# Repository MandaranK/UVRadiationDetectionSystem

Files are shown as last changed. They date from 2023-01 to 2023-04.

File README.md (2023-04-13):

# UVRadiationDetectionSystem
Designed to take solar radiation as a voltage input value through the light sensor.
Programmed to convert it into a UV index value, to be displayed and updated on an LCD monitor, in addition to informing the user how much skin protection is needed outside.
The STM32 Microcontroller was programmed in C, using the STM32Cube IDE.
The outer structure was designed in Autodesk AutoCAD and later 3D printed.

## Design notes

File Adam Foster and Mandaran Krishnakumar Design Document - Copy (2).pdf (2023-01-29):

Adam Foster, Mandaran Krishnakumar

ECE 198

Design Document

Needs Assessment

Client/Customer Definition

The Customer for which the product is being built is an Electrical Engineer from Kingston

Jamaica, who spends a lot of time outside the in the sun when on jobsites, for example inspecting

solar panel installations done by his company. Jamaica is known for its tropical climate;

however, the temperatures can get exceedingly high, especially in the summer months. This puts

him as well as his employees at a high risk of overexposure to UV radiation, which can have

multiple adverse health effects. The UV protection device designed is intended to reduce the

possibility of these health effects by measuring the UV radiation index and giving a

recommendation for the level of protection needed to safely work in these environments. The age

of the customer as well as his employees also puts them at an increased risk of these health

effects, thus it is vital that this device can give a good idea of the protection level needed in order

to work safely. The customer also suggested that the total cost of the device should not exceed

100 CAD, making it accessible to a wider demographic to ensure the safety of all those who

work in the sun.

Sources Cited

Walker, N. (2015, September 11). NEPA urges Jamaicans to practice better sun habits to

prevent skin and eye damage. NEPA. Retrieved October 31, 2022, from

https://websitearchive2020.nepa.gov.jm/new/media_centre/press_releases/releases/2015/P

R20150911-nepa_urges_jamaicans_to_practice_better_sun_habits.php (https://websitearchive2020.nepa.gov.jm/new/media_centre/press_releases/releases/2015/PR20150911-nepa_urges_jamaicans_to_practice_better_sun_habits.php)

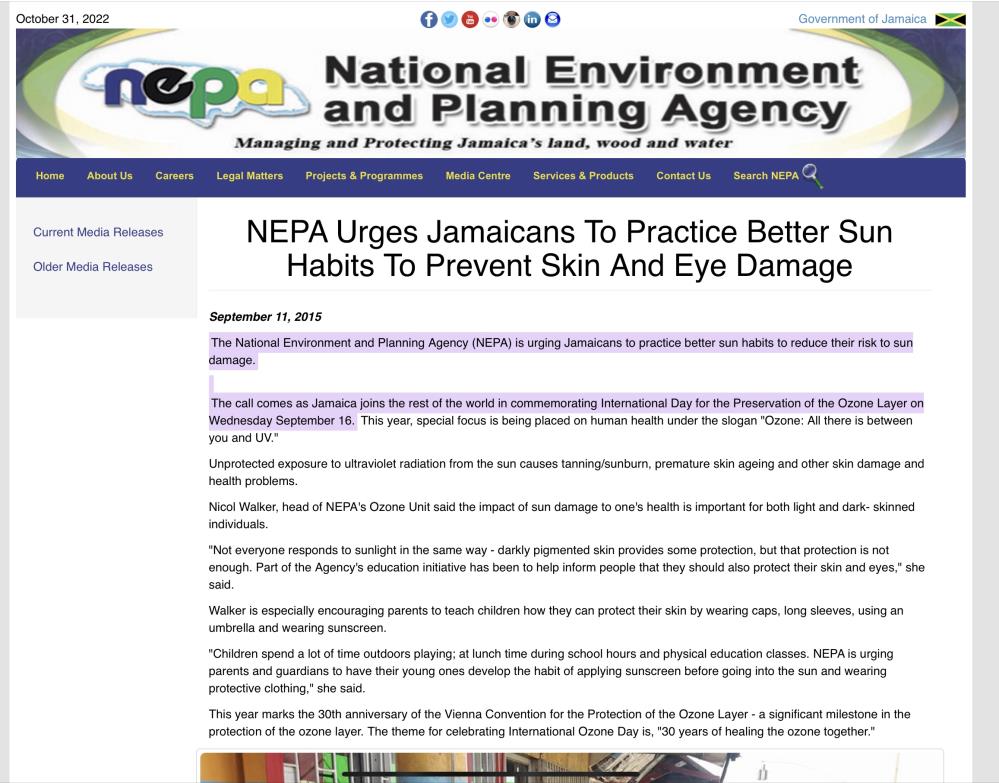
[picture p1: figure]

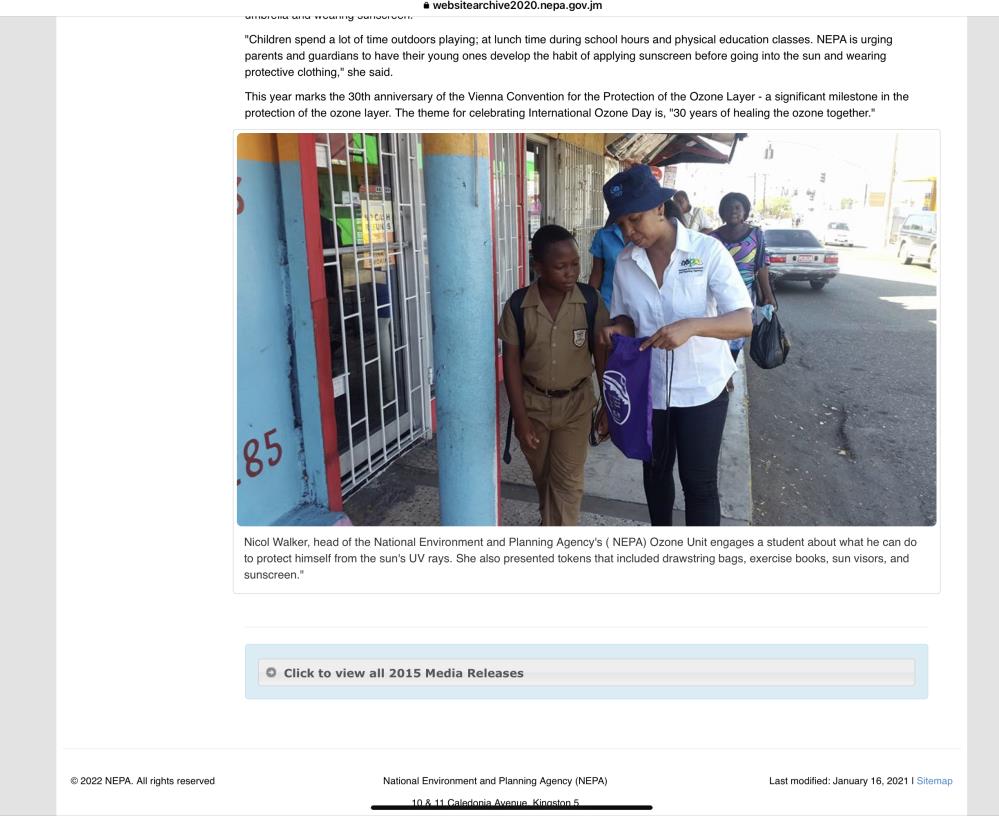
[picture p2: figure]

Rostant, H. (2001, July). Enjoy the fun, beware the sun. Caribbean Beat Magazine. Retrieved

October 31, 2022, from https://www.caribbean-beat.com/issue-50/enjoy-the-fun-beware-

the-sun#axzz7ifx9yx3c (https://www.caribbean-beat.com/issue-50/enjoy-the-fun-beware-the-sun#axzz7ifx9yx3c)

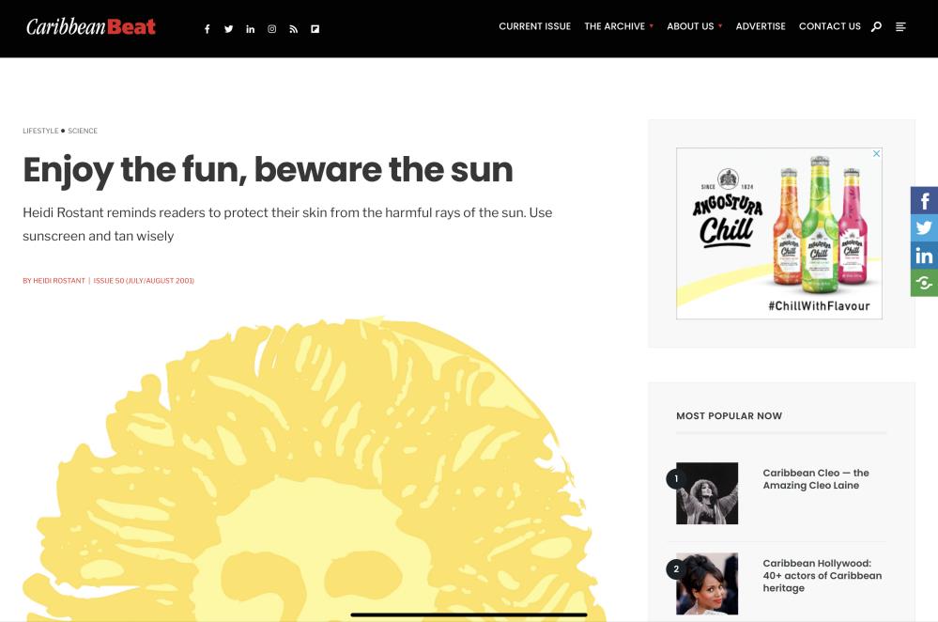
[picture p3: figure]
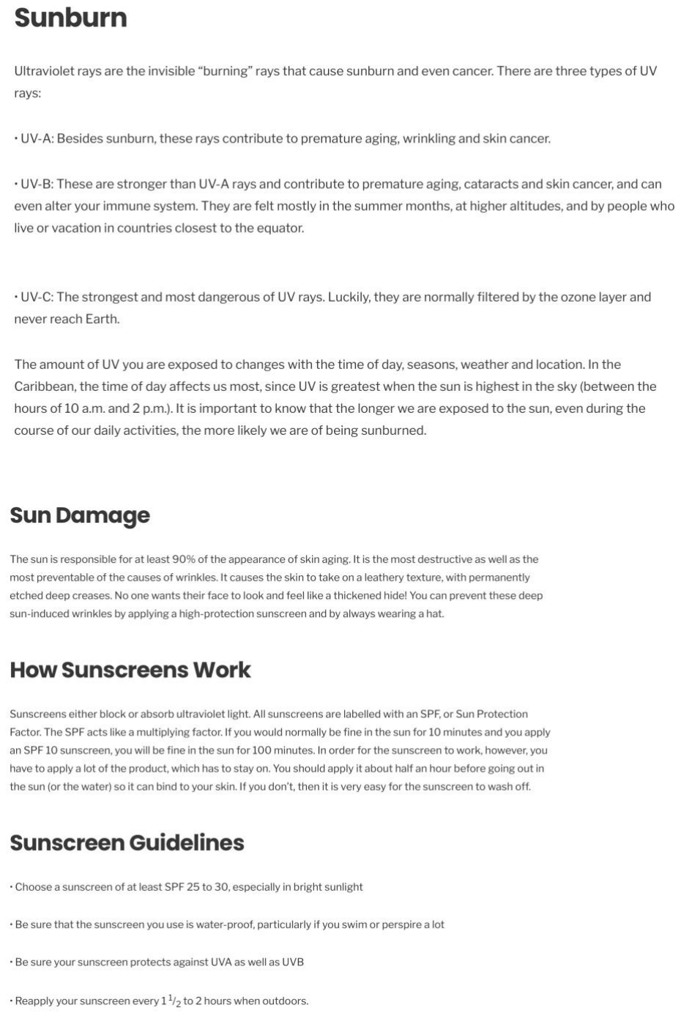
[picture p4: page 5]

Walker, N. (2009, January 27). The Ozone Layer and Jamaica's Role in Protecting It. National

Environment Planning Agency. Retrieved October 31, 2022, from

https://websitearchive2020.nepa.gov.jm/student/resource-

material/pdf/The_Ozone_Layer_and_Jamaica's_%20Role_in_Protecting_it.pdf (https://websitearchive2020.nepa.gov.jm/student/resource-material/pdf/The_Ozone_Layer_and_Jamaica's_%20Role_in_Protecting_it.pdf)

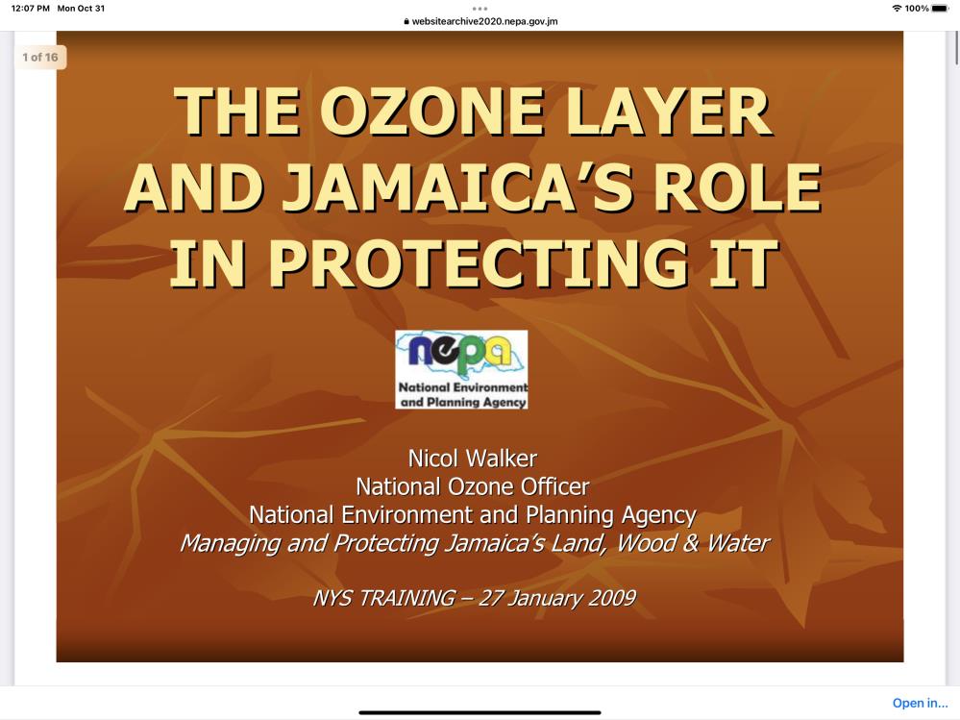
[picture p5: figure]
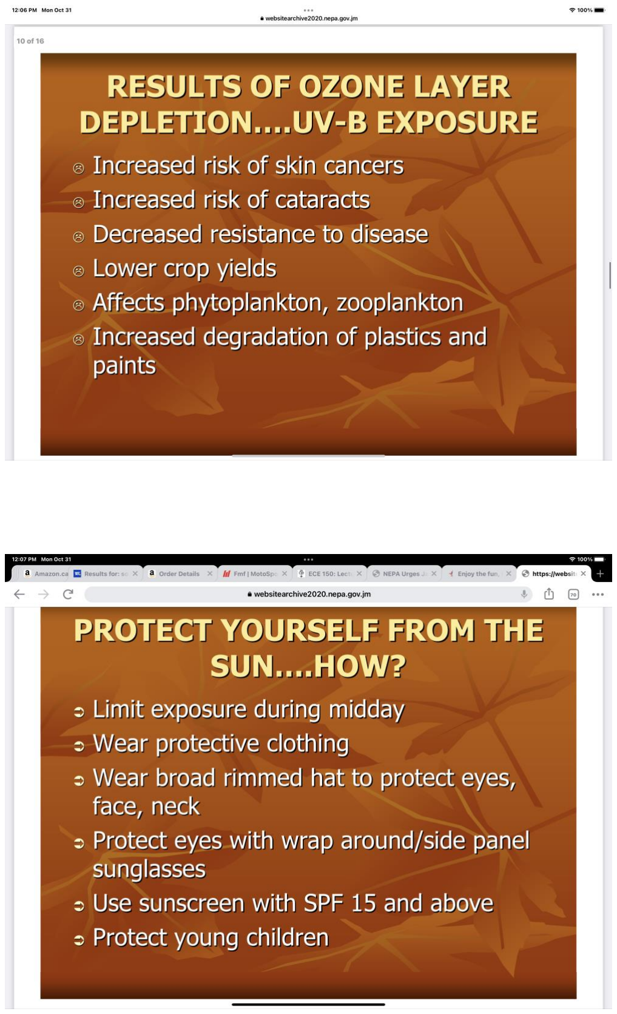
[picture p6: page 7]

Competitive Landscape

Technological System 1 (UV Global App)

The SunSmart UV Global app provides the customer with daily forecasts of UV radiation and

weather for different locations around the world. The app provides time intervals during the day

when sun protection is required, for the purpose of reducing the amount of global skin cancer

and eye damage.

The shortcoming of this system is based around the accuracy of the readings on the app. Due to

fluctuations with cloud coverage within the same general area, this app might not be able to

provide the correct UV index for the precise location the customer is in. Moreover, this app

might not update as frequently as a customer might need when moving from one area to another

in the same general location.

Haysmith, S. E. (2022, June 21). SunSmart Global UV app helps protect you from the dangers of

the Sun and promotes public health. World Health Organization. Retrieved October 31,

2022, from https://www.who.int/news/item/21-06-2022-sunsmart-global-uv-app-helps-

protect-you-from-the-dangers-of-the-sun-and-promotes-public-

health#:~:text=The%20SunSmart%20Global%20UV%20app,and%20UV%2Drelated%20e

ye%20damage. (https://www.who.int/news/item/21-06-2022-sunsmart-global-uv-app-helps-protect-you-from-the-dangers-of-the-sun-and-promotes-public-health)

Technological System 2 (Arduino UV Index Meter Created by Abid Hossain)

The Arduino UV Index Meter created by Abid Hossain, solves most of the challenges presented.

It uses a UV index sensor along with an Arduino and a display to read and output the numeric

value of the UV index along with a relative measurement.

This solution seems viable, however, when taking a closer look, we can see that the formfactor is

not one that makes the device portable. The two breadboards along with the need for an external

power supply do not allow for the device to be used easily in a work environment. This along with

the fact that it is not protected within an enclosure does not make it a suitable solution.

Hossain, A. (2021, May 28). Arduino UV index meter. Arduino Project Hub. Retrieved October

31, 2022, from https://create.arduino.cc/projecthub/abid_hossain/arduino-uv-index-meter-

f03b4e (https://create.arduino.cc/projecthub/abid_hossain/arduino-uv-index-meter-f03b4e)

Technological System 3 (UV Index Meter created by DroneBot Workshop)

The UV index meter created by DroneBot Workshop is another solution that encompasses most

of the requirements specified by the customer, namely measuring and outputting the UV index to

a display, as well as the integration of a portable power source. In addition, it is also able to read

the temperature and humidity, which was not specified as a requirement from the customer.

As with the last design this one also has a few drawbacks. The device is again not enclosed

which results in it being more difficult to use and not adequately protecting the components. The

additional components that are also added allowing for the temperature and humidity to be

measured also use more of the microcontroller's memory and add more complexity to the system.

The lack of a rechargeable power source may also be a disadvantage in the eyes of the customer.

Workshop, D. B. (2018, September 5). Build an Arduino UV index meter. DroneBot Workshop.

Retrieved October 31, 2022, from https://dronebotworkshop.com/arduino-uv-index-meter/

Requirement Specification

- The device should feature the ability to calculate and output the UV index of the

ultraviolet radiation (using the GUVA S12SD UV Light Sensor Breakout) which is

initially measured in voltage then converted to a UV index value ranging from 1 – 11.

- The device should refresh the reading of the UV index and the required protection every

5000 ms.

- The device should read the sun’s UV radiation level in terms of a value from 1 – 11, and

output the UV Index value and the necessary level of protection to prevent overexposure

to high UV radiation levels.

- The device should boot up and display the UV rating and necessary protection needed

within 2000 ms of the power switch being turned on.

- The software should have the ability to convert the voltage value recorded by the UV

sensor to a UV index value by dividing the output voltage by 0.1V.

Analysis

Design

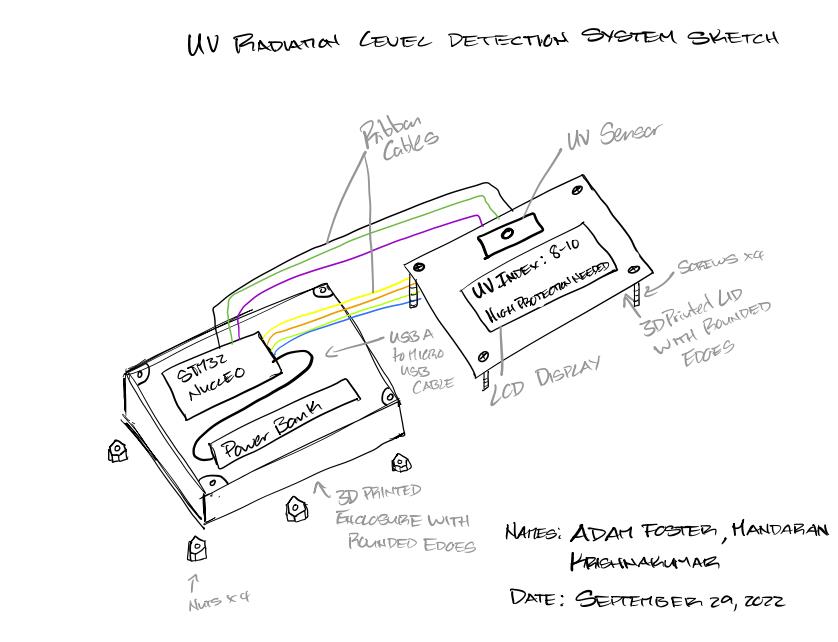
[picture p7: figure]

The Design of the UV index measurement device comprises of 18 main parts. These include:

- The STM 32 Nucleo 64 Board
- The 3D Printed Enclosure
- The 3D Printed Lid
- The UV sensor

- The LCD Display
- The Connecting Wires
- The Power Bank
- The Mini USB to USB A cable
- The Four bolts
- The Four nuts
- 10k Potentiometer
- 100 ohm resistor

The device is assembled by first making the connections using the connecting wires based on the

wiring diagram illustrated below.

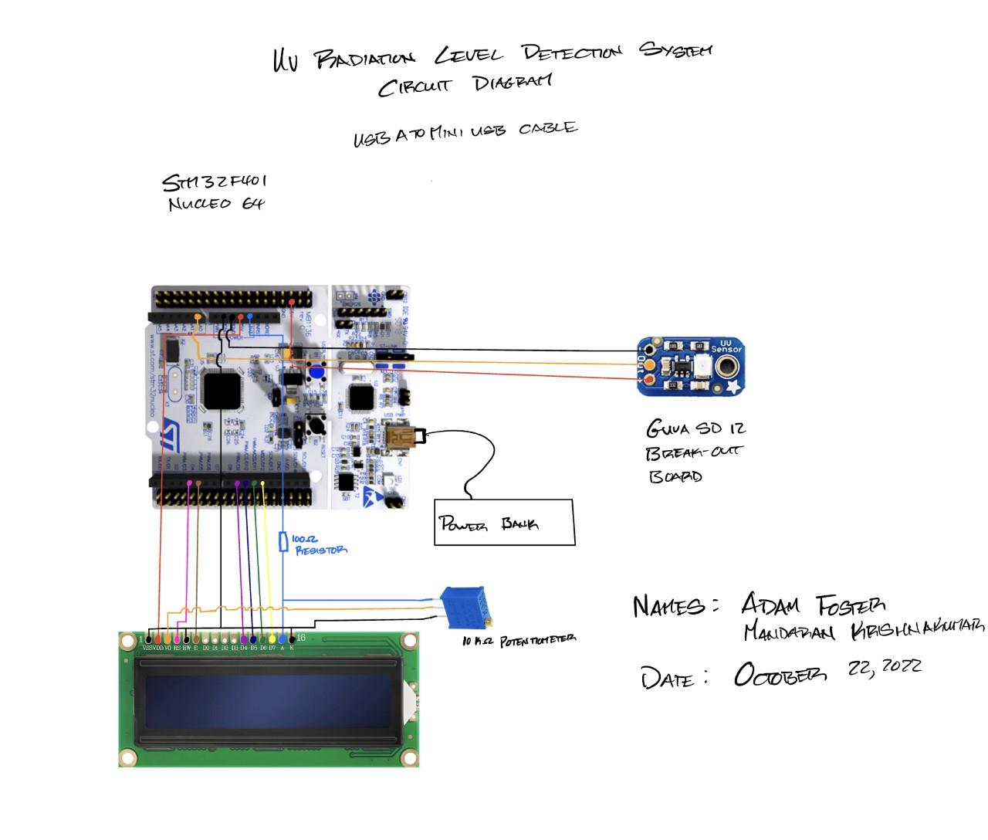
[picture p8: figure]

Next the components can be placed into the 3D printed enclosure. The LCD screen and the UV

sensor can then be attached to the lid of the enclosure using low temperature hot glue.

To complete the assembly of the device, the lid can be placed on top of the enclosure with the

display and UV sensor facing outward and the four bolts can be passed through the lid and the

through the enclosure. The entire assembly is held together using four nuts, one on each bolt

passed though the enclosure.

To operate the device, the power bank must first be switched on. At this point the

microcontroller will boot up and numerical values for the UV index and the corresponding amount of protection that will be needed to remain safe will be displayed. This value will update

every 5000 ms. It is important to ensure that the device is not placed in a shaded area to ensure

the accuracy of the readings received. Once the user has collected adequate readings, the device

can be powered down by turning off the power bank.

Scientific or Mathematical Principles

Arithmetic

- Fundamental theorem of arithmetic: The UV sensor output voltage will be divided by a

factor of 0.1 to calculate the equivalent UV index value.

Equation: UV index = output voltage / 0.1 V

Industries, A. (n.d.). Analog UV light sensor breakout - guva-S12SD. adafruit industries blog

RSS. Retrieved October 31, 2022, from https://www.adafruit.com/product/1918

Electromagnetism

- Electric Potential: The device’s UV sensor will output an electric potential value that can

be used to calculate the UV index value.

Equation: UV index value = output electric potential / 0.1 V

Industries, A. (n.d.). Analog UV light sensor breakout - guva-S12SD. adafruit industries blog

RSS. Retrieved October 31, 2022, from https://www.adafruit.com/product/1918

Statistics

- Statistical Distribution: The device will be able to record UV index values over time and

output the maximum and minimum values recorded, as well as the median UV index.

This will give an idea of the variation in solar radiation.

Maximum UV Index = highest voltage / 0.1 V

Minimum UV Index = lowest voltage / 0.1 V

Median UV Index = (Maximum UV Index + Minimum UV Index) / 2

Brooks, D. R. (2021). Arduino-based UV Measurements Institute for earth ... - instesre.org.

Arduino-Based UV Measurements. Retrieved October 31, 2022, from

https://instesre.org/ArduinoBook/UVmeasurements.pdf

Costs

Manufacturing Costs

In manufacturing the UV Index measurement device, there were many costs associated with

manufacturing the final product. As far as the manufacturer locations are concerned, the UV

index sensor is made by Adafruit Industries located in New York City, the power bank is

manufactured by Shenzhen Firstar Battery Co., Limited located in Shenzhen China, the 3D

printer used was manufactured by Prusa Research located in Prague, Czech Republic, the nuts

and bolts were manufactured by Home Builder a Home Hardware Brand which is located in

Waterloo, Ontario and the other electronic components were manufactured by Elegoo, located in

Shenzhen China.

Most of the items used in the project are available on Amazon, which allows for them to be

easily shipped to most parts of the world allowing for the device to be easily replicated. The only

exceptions are the 3D printer and printing material as well as the nuts and bolts. The 3D printer

is available from Prusa Research directly. This may be less accessible due to the company being

located in the Czech Republic, and the device itself being very costly however there are

companies that are making 3D printing more accessible, with cheaper printers being available on

Amazon, as well as printing services that are a fraction of the cost of a 3D printer. The bolts

although manufactured by a company based in Ontario can be found at any local hardware store

in most parts of the world.

Implementation Costs

To operate the UV Index Measurement device:

- Place it on a level surface with the UV sensor facing directly upward.
- Power on the device using the button located on the back.
- Read the UV index value and the relative protection measurement and ensure that the

necessary protection is used while in the sun

- To recharge the battery, remove the four nuts from the bottom of the device and remove

the lid.

- Use the included micro USB cable to charge the power bank.

- Once charged, unplug the power bank and reassemble the device by replacing the lid with

the four bolts and fastening the nuts on the bottom of the device.

- To make any changes to the program, disassemble the device using the steps above, plug

the included mini USB cable into the STM 32 Nucleo 64 board and the other end into a

computer.

- Make any necessary changes using the STM Cube IDE.

Risks

Energy Analysis

Based on the requirements given in the project requirements document, the design must not

consume, transfer discharge or otherwise expend more than 30W of power at any point in time

and the design must also not store or otherwise contain more than 500 mJ of energy at any point

in time.

The device is powered by a power bank that supplies 5V at 2.4A to the STM 32 microcontroller.

This therefore means that the output power of the power bank is 12W, which is well below the

30W threshold. The input power needed to charge the power bank is 10W which is also below

the 30W threshold. Although a 110V AC power adapter can be used to charge the power bank,

by connecting it to the included micro-USB cable, it is recommended that a laptop’s USB port is

used to charge the power bank as it is much safer than using an AC power supply due to the

voltages being much lower. Although the power bank stores approximately 67 KJ of energy, this

could be considered an external component, because the STM 32 along with all the other

components within the circuit do not allow for more than 500 mJ of energy to be stored.

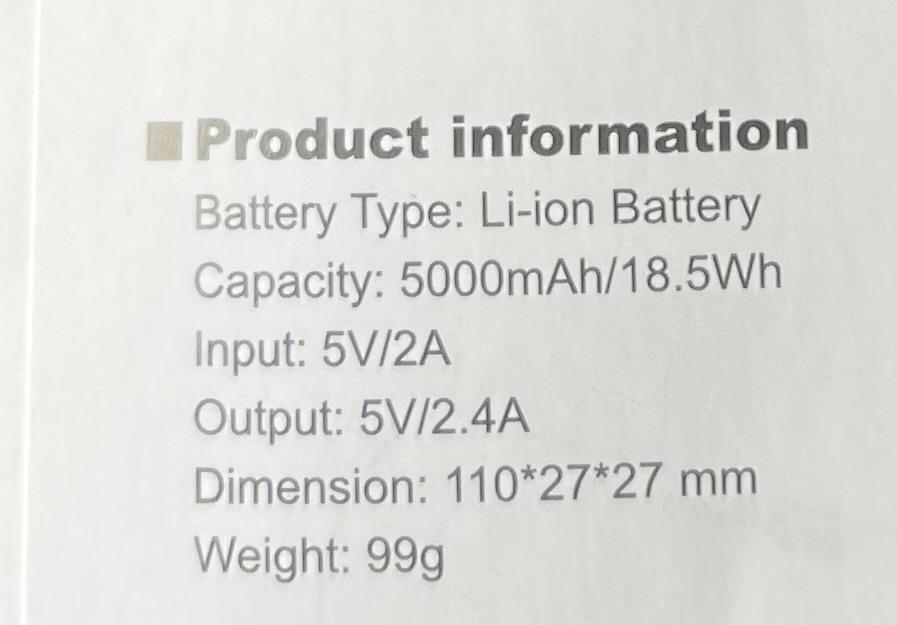
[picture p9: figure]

Image taken from Energy QC Power Bank Manual

Since there are no mechanical moving parts, there is no storage of mechanical energy. There are

also no capacitors or other energy storage devices, apart from the power bank, that would allow

for the build up of energy greater than 500 mJ in the internal system of the device. The UV

sensor can sense up to a UV index of 11, which equates to 1.1 V.

If this corresponds to a photocurrent of 1uA and is stored for 1 second, then the energy stored

would be 1.1 x 10 ⁻⁶
J

which is well below the 500 mJ threshold.

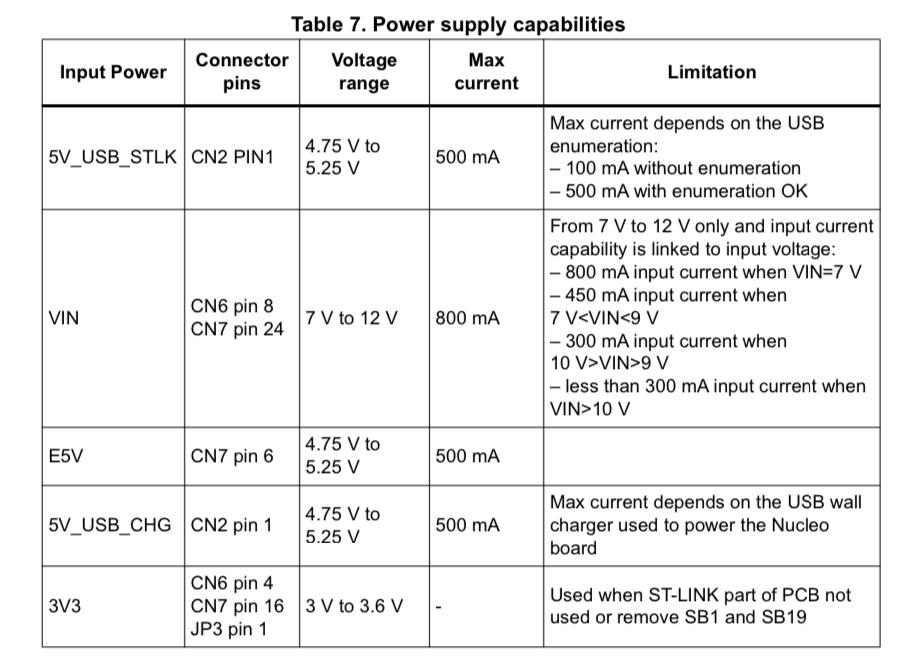
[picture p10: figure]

Image taken from STM 32 Nucleo 64 Manual

Risk Analysis

1. If the design is used as intended, the only negative consequence that may occur is the

usage of energy to recharge the battery within the device.

2. If the design is not used as intended, there is the possibility of a short circuit being

created by introducing moisture to the system or placing bare wires directly on a metal

surface which could cause damage to the components and potentially electrocute the user.

3. The device could overheat and potentially shut down if exposed to very high

temperatures for an extended period. This could also cause the battery to overheat and

even explode causing harm to people near the device.

4. The design could malfunction by one or several of the internal connections becoming

loose. This could result in the display not working correctly or the UV index

measurement being inaccurate.

5. If the internal connections become loose, this could cause a short circuit and potentially a

fire. It could also cause an incorrect measurement to be displayed which could result in

the overexposure of the user to UV radiation.

Testing and Validation

Test Plan

Requirement:

- The device should feature the ability to calculate and output the UV index of the

ultraviolet radiation (using the GUVA S12SD UV Light Sensor Breakout) which is

initially measured in voltage then converted to a UV index value.

Test:

- The test is set up by powering on the UV index measurement device and placing it on a

horizontal surface in the sun that has no shading. The environmental parameter being

measured is the UV index. The test input is the sunshine which will be converted to a

voltage value that can be understood by the microcontroller. The value output by the

display can be compared to that of another UV index meter that is set up in the same

place. Once the values are within 1.0 unit of each other, the test has been passed.

Requirement:

- The device should refresh the reading of the UV index and the required protection every

5000 ms.

Test:

- The test is set up by powering on the UV index measurement device and placing it on a

horizontal surface in the sun that has no shading. Using a stopwatch, for three readings,

measure the time between each update and find the average of three time readings. The

environmental parameter being measured is the time between the output of the UV index

readings. The test input is the sunshine that is converted to a UV index reading and

displayed to the screen. Once the value is within 500 ms of 5000 ms, to account for

reaction time, then the test has been passed.

Requirement:

- The device should read the sun’s UV radiation level and output the UV rating and the

necessary level of protection to prevent overexposure to high UV radiation levels.

Test:

- The test is set up by powering on the UV index measurement device and placing it on a

horizontal surface in the sun that has no shading. The environmental parameter being

measured is the relative UV protection needed. The test input is the sunshine which can

be converted to voltages that can be understood by the microcontroller. Using an app that

gives the relative protection value needed to keep safe, record the measurement that is

displayed. Once the necessary protection is similar in a relative sense then the test has

been passed.

Requirement:

- The device should boot up and display the UV index measurement and necessary

protection needed within 2000 ms of the power switch being turned on.

Test:

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

horizontal surface in the sun that has no shading. The environmental parameter being

measured is the time taken for the device to boot up and display the UV index value and

necessary protection needed. The test input is the sunshine which is converted to a

voltage value that can be understood by the microcontroller. If the UV index device is

able to boot up and display the UV index and the relative protection value in less than

2000ms then the test has been passed.

Requirement:

- The software should have the ability to convert the voltage value recorded by the UV

sensor to a UV index value by dividing the output voltage by 0.1V.

Test:

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

horizontal surface in the sun that has no shading. The environmental parameter being

measured is the UV index value. The test input is the sunshine and the UV index value

output before it is divided by 0.1 V. Three measurements can be recorded by outputting

the raw value from the UV index sensor to the display by modifying the code. Another

UV index measurement device can be set up in the same location and the values output

by it recorded. If the output when divided by 0.1V manually is within 1.0 of that of the

other UV index measurement device, then the test has been passed.

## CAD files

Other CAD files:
UV Index Measurement Device Lid Revision 2 Nov 17 2022.dwg
UV Index Measurement Device Enclosure Revision 2 Nov 17 2022.dwg

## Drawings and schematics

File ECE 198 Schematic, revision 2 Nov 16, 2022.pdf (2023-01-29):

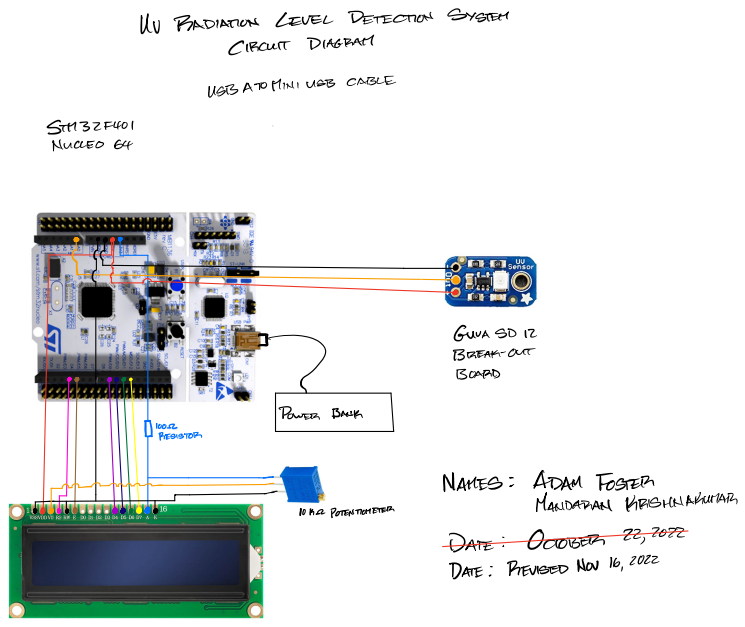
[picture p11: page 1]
CIRCUIT DIAGRAM; USBATOMINIUSB CABLE; STM321401 NUCLEO 64; GUASD 12 BREAKOUT BOARD; PowerBank; Dioggistom; g Iftar; MANDARAN KRISHNAKUTA; 10hrPOTENTIOMETER; Date October 2217022 DATE REVISEDNOV16,2022

NAMES ADAM FOSTER

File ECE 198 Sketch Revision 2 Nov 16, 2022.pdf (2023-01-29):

# jiffy

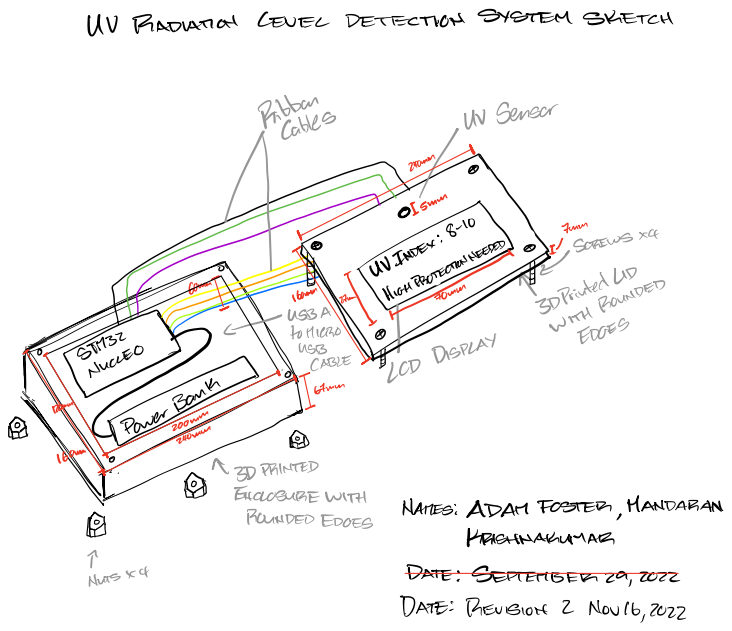
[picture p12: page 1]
EDGES; 81 ENCLOSUREWITH; ROUNDEDEDGES; Its44; DATE SEPTEMBER 29 2022; DATE REVISION 2 Nov16,2022

Detection SYSTEM sketch

NAMES ADAM FOSTER MANDARA
KRISHNAKUMAR

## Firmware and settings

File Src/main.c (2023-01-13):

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
/* Includes ------------------------------------------------------------------*/
#include "main.h"

/* USER CODE BEGIN Includes */
#include "lcd.h"
#include <string.h>
#include <stdio.h>
/* USER CODE END Includes */

ADC_HandleTypeDef hadc1;

UART_HandleTypeDef huart2;

void SystemClock_Config(void);
static void MX_GPIO_Init(void);
static void MX_USART2_UART_Init(void);
static void MX_ADC1_Init(void);
/* USER CODE BEGIN 0 */
uint32_t adcVal0;
ADC_ChannelConfTypeDef sConfig = {0};

/* USER CODE END 0 */

/**
  * @brief  The application entry point.
  * @retval int
  */
int main(void)
{
  /* MCU Configuration--------------------------------------------------------*/

  /* Reset of all peripherals, Initializes the Flash interface and the Systick. */
  HAL_Init();

  /* Configure the system clock */
  SystemClock_Config();

  /* Initialize all configured peripherals */
  MX_GPIO_Init();
  MX_USART2_UART_Init();
  MX_ADC1_Init();
  /* USER CODE BEGIN 2 */
  // Lcd_PortType ports[] = { D4_GPIO_Port, D5_GPIO_Port, D6_GPIO_Port, D7_GPIO_Port };
    Lcd_PortType ports[] = { GPIOC, GPIOB, GPIOA, GPIOA };
    // Lcd_PinType pins[] = {D4_Pin, D5_Pin, D6_Pin, D7_Pin};
    Lcd_PinType pins[] = {GPIO_PIN_7, GPIO_PIN_6, GPIO_PIN_7, GPIO_PIN_6};
    Lcd_HandleTypeDef lcd;
    // Lcd_create(ports, pins, RS_GPIO_Port, RS_Pin, EN_GPIO_Port, EN_Pin, LCD_4_BIT_MODE);
    lcd = Lcd_create(ports, pins, GPIOB, GPIO_PIN_5, GPIOB, GPIO_PIN_4, LCD_4_BIT_MODE);
    Lcd_cursor(&lcd, 0,0);
    Lcd_string(&lcd, "UV Index: ");
    Lcd_cursor(&lcd, 1,0);
    Lcd_string(&lcd, "Protection: ");
   /*   for ( int x = 1; x <= 200 ; x++ )
      {
        Lcd_cursor(&lcd, 1,7);
        Lcd_int(&lcd, x);
        HAL_Delay (1000);
      }*/



  /* USER CODE END 2 */

  /* Infinite loop */
  /* USER CODE BEGIN WHILE */
  while (1)
  {
    /* USER CODE END WHILE */

    /* USER CODE BEGIN 3 */
        HAL_ADC_Start(&hadc1);
        if(HAL_ADC_PollForConversion(&hadc1, 5) == HAL_OK){
              adcVal0 = HAL_ADC_GetValue(&hadc1);
        }
             Lcd_cursor(&lcd, 0,10);
             if(adcVal0 >= 11){
                   Lcd_int(&lcd, 11);
             }
             else {
                  Lcd_int(&lcd, adcVal0);
             }


            if (adcVal0 >= 11){
                  Lcd_cursor(&lcd, 1,11);
                  Lcd_string(&lcd, "EXT! ");
            }
            else if (adcVal0 < 11 && adcVal0 >= 8){
                  Lcd_cursor(&lcd, 1,11);
                  Lcd_string(&lcd, "VHigh");
            }
            else if (adcVal0 < 8 && adcVal0 >= 6){
                  Lcd_cursor(&lcd, 1,11);
                  Lcd_string(&lcd, "High ");
            }
            else if (adcVal0 < 6 && adcVal0 >= 3){
                  Lcd_cursor(&lcd, 1,11);
                  Lcd_string(&lcd, "Med  ");
            }
            else if (adcVal0 < 2 && adcVal0 > 0){
                  Lcd_cursor(&lcd, 1,11);
                  Lcd_string(&lcd, "Low  ");
            }
            else if (adcVal0 == 0 ){
                  Lcd_cursor(&lcd, 1,11);
                  Lcd_string(&lcd, "None ");
            }
             HAL_Delay(1000);
             Lcd_cursor(&lcd, 0,10);
             Lcd_string(&lcd,"      ");
  }
  /* USER CODE END 3 */
}

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


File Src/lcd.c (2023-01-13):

/*
 * lcd.c
 *
 */

#include "lcd.h"
const uint8_t ROW_16[] = {0x00, 0x40, 0x10, 0x50};
const uint8_t ROW_20[] = {0x00, 0x40, 0x14, 0x54};
/************************************** Static declarations **************************************/

static void lcd_write_data(Lcd_HandleTypeDef * lcd, uint8_t data);
static void lcd_write_command(Lcd_HandleTypeDef * lcd, uint8_t command);
static void lcd_write(Lcd_HandleTypeDef * lcd, uint8_t data, uint8_t len);


/************************************** Function definitions **************************************/

/**
 * Create new Lcd_HandleTypeDef and initialize the Lcd
 */
Lcd_HandleTypeDef Lcd_create(
            Lcd_PortType port[], Lcd_PinType pin[],
            Lcd_PortType rs_port, Lcd_PinType rs_pin,
            Lcd_PortType en_port, Lcd_PinType en_pin, Lcd_ModeTypeDef mode)
{
      Lcd_HandleTypeDef lcd;

      lcd.mode = mode;

      lcd.en_pin = en_pin;
      lcd.en_port = en_port;

      lcd.rs_pin = rs_pin;
      lcd.rs_port = rs_port;

      lcd.data_pin = pin;
      lcd.data_port = port;

      Lcd_init(&lcd);

      return lcd;
}

/**
 * Initialize 16x2-lcd without cursor
 */
void Lcd_init(Lcd_HandleTypeDef * lcd)
{
      if(lcd->mode == LCD_4_BIT_MODE)
      {
                  lcd_write_command(lcd, 0x33);
                  lcd_write_command(lcd, 0x32);
                  lcd_write_command(lcd, FUNCTION_SET | OPT_N);                     // 4-bit mode
      }
      else
            lcd_write_command(lcd, FUNCTION_SET | OPT_DL | OPT_N);


      lcd_write_command(lcd, CLEAR_DISPLAY);                                  // Clear screen
      lcd_write_command(lcd, DISPLAY_ON_OFF_CONTROL | OPT_D);           // Lcd-on, cursor-off, no-blink
      lcd_write_command(lcd, ENTRY_MODE_SET | OPT_INC);                 // Increment cursor
}

/**
 * Write a number on the current position
 */
void Lcd_int(Lcd_HandleTypeDef * lcd, int number)
{
      char buffer[11];
      sprintf(buffer, "%d", number);

      Lcd_string(lcd, buffer);
}

/**
 * Write a string on the current position
 */
void Lcd_string(Lcd_HandleTypeDef * lcd, char * string)
{
      for(uint8_t i = 0; i < strlen(string); i++)
      {
            lcd_write_data(lcd, string[i]);
      }
}

/**
 * Set the cursor position
 */
void Lcd_cursor(Lcd_HandleTypeDef * lcd, uint8_t row, uint8_t col)
{
      #ifdef LCD20xN
      lcd_write_command(lcd, SET_DDRAM_ADDR + ROW_20[row] + col);
      #endif

      #ifdef LCD16xN
      lcd_write_command(lcd, SET_DDRAM_ADDR + ROW_16[row] + col);
      #endif
}

/**
 * Clear the screen
 */
void Lcd_clear(Lcd_HandleTypeDef * lcd) {
      lcd_write_command(lcd, CLEAR_DISPLAY);
}

void Lcd_define_char(Lcd_HandleTypeDef * lcd, uint8_t code, uint8_t bitmap[]){
      lcd_write_command(lcd, SETCGRAM_ADDR + (code << 3));
      for(uint8_t i=0;i<8;++i){
            lcd_write_data(lcd, bitmap[i]);
      }

}


/************************************** Static function definition **************************************/

/**
 * Write a byte to the command register
 */
void lcd_write_command(Lcd_HandleTypeDef * lcd, uint8_t command)
{
      HAL_GPIO_WritePin(lcd->rs_port, lcd->rs_pin, LCD_COMMAND_REG);          // Write to command register

      if(lcd->mode == LCD_4_BIT_MODE)
      {
            lcd_write(lcd, (command >> 4), LCD_NIB);
            lcd_write(lcd, command & 0x0F, LCD_NIB);
      }
      else
      {
            lcd_write(lcd, command, LCD_BYTE);
      }

}

/**
 * Write a byte to the data register
 */
void lcd_write_data(Lcd_HandleTypeDef * lcd, uint8_t data)
{
      HAL_GPIO_WritePin(lcd->rs_port, lcd->rs_pin, LCD_DATA_REG);             // Write to data register

      if(lcd->mode == LCD_4_BIT_MODE)
      {
            lcd_write(lcd, data >> 4, LCD_NIB);
            lcd_write(lcd, data & 0x0F, LCD_NIB);
      }
      else
      {
            lcd_write(lcd, data, LCD_BYTE);
      }

}

/**
 * Set len bits on the bus and toggle the enable line
 */
void lcd_write(Lcd_HandleTypeDef * lcd, uint8_t data, uint8_t len)
{
      for(uint8_t i = 0; i < len; i++)
      {
            HAL_GPIO_WritePin(lcd->data_port[i], lcd->data_pin[i], (data >> i) & 0x01);
      }

      HAL_GPIO_WritePin(lcd->en_port, lcd->en_pin, 1);
      DELAY(1);
      HAL_GPIO_WritePin(lcd->en_port, lcd->en_pin, 0);            // Data receive on falling edge
}

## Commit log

2025-07-30 Rename Ece 198 schematic, revision 2 Nov 16, 2022.pdf to Schematic, revision 2 Nov 16, 2022.pdf
2025-07-30 Rename Schematic, revision 2 Nov 16, 2022.pdf to ECE 198 Schematic, revision 2 Nov 16, 2022.pdf

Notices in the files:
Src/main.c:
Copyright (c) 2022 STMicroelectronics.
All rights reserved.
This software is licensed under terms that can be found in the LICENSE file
